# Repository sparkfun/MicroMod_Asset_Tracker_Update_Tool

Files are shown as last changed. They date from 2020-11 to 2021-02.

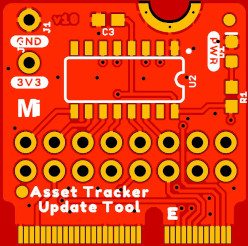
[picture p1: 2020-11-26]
img/Top.JPG

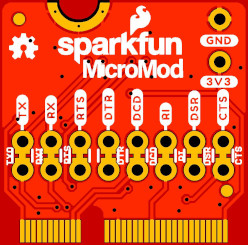
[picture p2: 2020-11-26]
img/Bottom.JPG

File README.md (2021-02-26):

# MicroMod Asset Tracker Firmware Update Tool

SparkFun MicroMod Update Tool (https://www.sparkfun.com/products/17725)

[*SparkFun MicroMod Update Tool (DEV-17725)*](https://www.sparkfun.com/products/17725)

A dummy Processor Board which will simplify firmware updates for the SARA-R5 on the [MicroMod Asset Tracker Carrier Board](https://www.sparkfun.com/products/17272).

The board carries a CH340C USB-Serial converter to act as the bridge between the USB-C interface on the carrier board and the 8-wire UART interface on the SARA-R5.

Power for the SARA can be enabled via a push-button on the carrier board.

The firmware can be updated with [EasyFlash](https://www.u-blox.com/sites/default/files/SARA-R5-FW-Update_AppNote_%28UBX-20033314%29.pdf).

The tool will also make it easy for anyone wanting to use [m-center](https://www.u-blox.com/en/product/m-center) to communicate with the SARA.

## Repository Contents

* **/Hardware** - Eagle PCB, SCH and LBR design files
* **LICENSE.md** contains the licence information

## Documentation

* **[Hookup Guide](https://learn.sparkfun.com/tutorials/micromod-update-tool-hookup-guide)** - A basic Hookup Guide for the MicroMod Update Tool.
* **[Getting Started with MicroMod](https://learn.sparkfun.com/tutorials/getting-started-with-micromod)** - A tutorial to help you get started with the MicroMod Ecosystem.
* **[Designing with MicroMod](https://learn.sparkfun.com/tutorials/designing-with-micromod)** - A tutorial to walk you through the specs of the MicroMod processor and carrier board as well as the basics of incorporating the MicroMod form factor into your own PCB designs.

## Product Versions

* **[DEV-17725](https://www.sparkfun.com/products/17725)** - Initial release of the MicroMod Update Tool

## License Information

This product is _**open source**_!

Please review the LICENSE.md file for license information.

If you have any questions or concerns on licensing, please contact technical support on our [SparkFun forums](https://forum.sparkfun.com/viewforum.php?f=152).

Distributed as-is; no warranty is given.

- Your friends at SparkFun.

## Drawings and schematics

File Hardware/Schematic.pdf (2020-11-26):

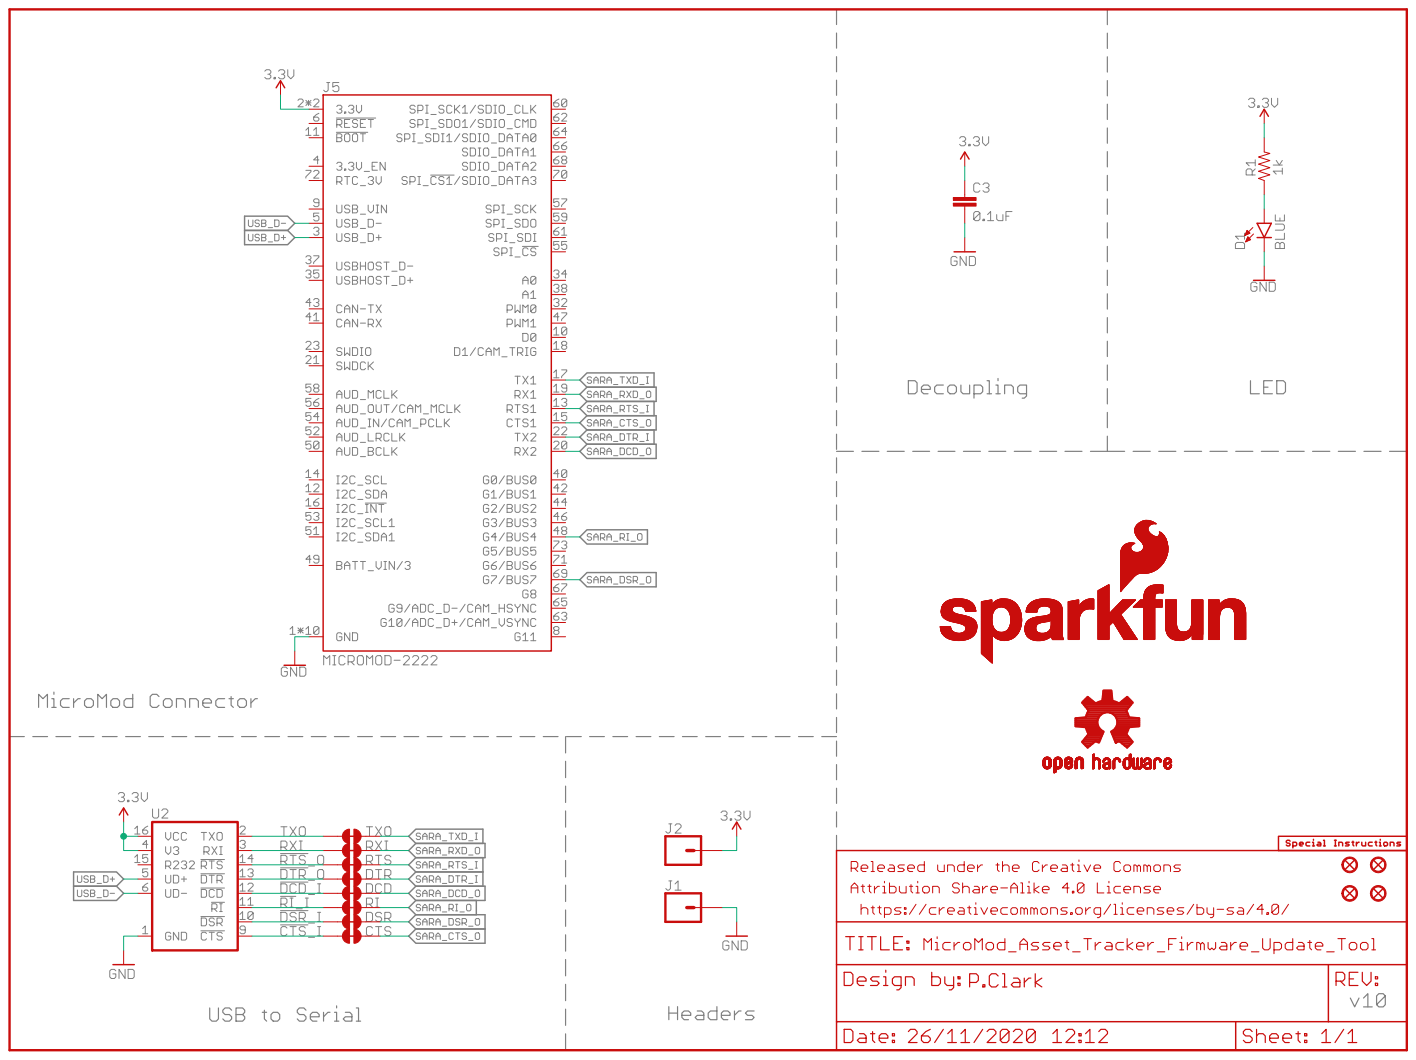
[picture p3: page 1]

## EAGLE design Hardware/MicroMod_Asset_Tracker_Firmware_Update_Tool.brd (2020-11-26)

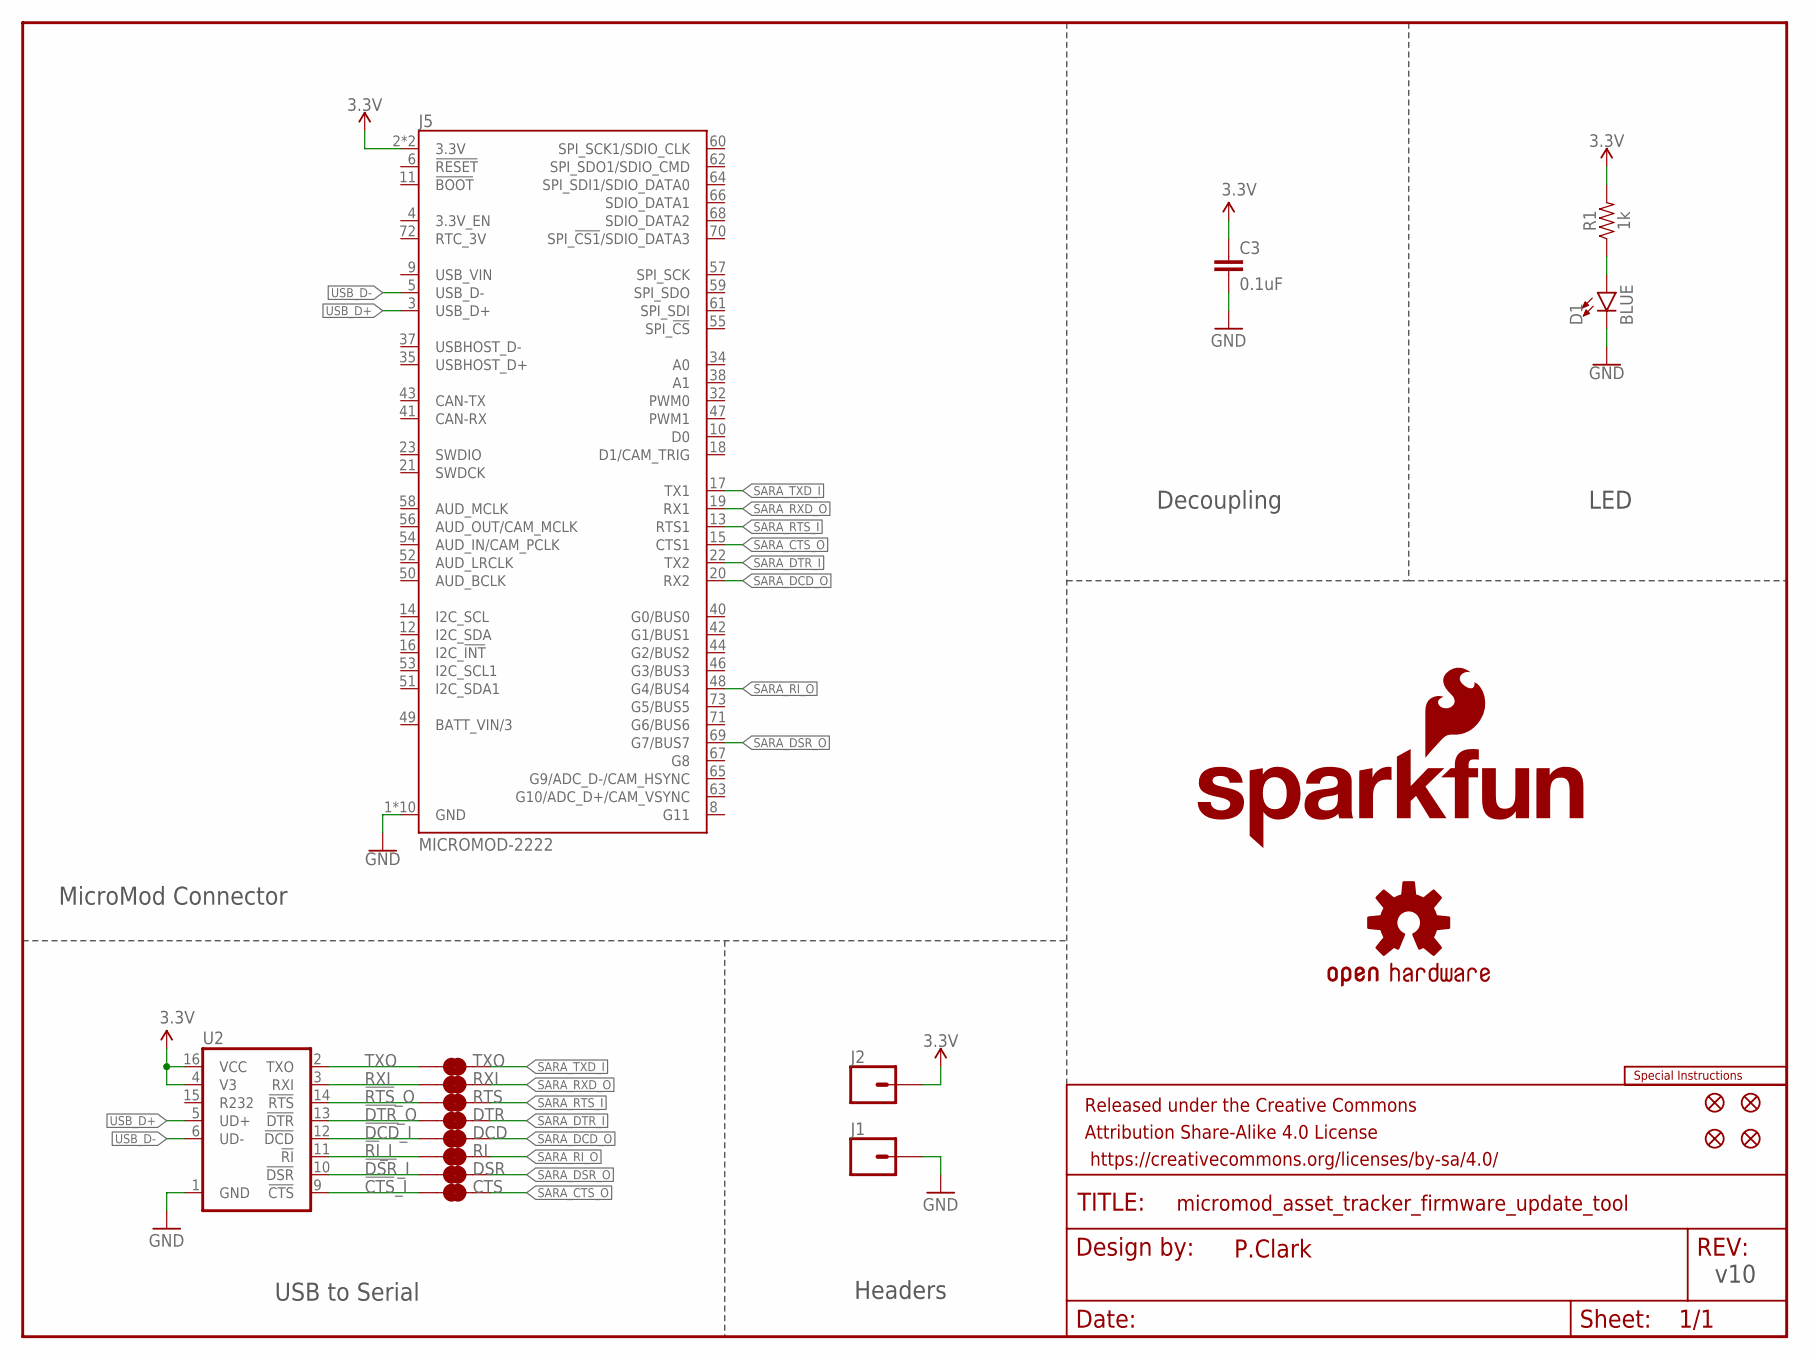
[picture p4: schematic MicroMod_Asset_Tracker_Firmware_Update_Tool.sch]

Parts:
C3: 0.1uF; 0603
CTS: JUMPER-COMBO_2_NC_TRACE; COMBO-JUMPER_2_NC_TRACE
D1: BLUE; LED-0603
DCD: JUMPER-COMBO_2_NC_TRACE; COMBO-JUMPER_2_NC_TRACE
DSR: JUMPER-COMBO_2_NC_TRACE; COMBO-JUMPER_2_NC_TRACE
DTR: JUMPER-COMBO_2_NC_TRACE; COMBO-JUMPER_2_NC_TRACE
FRAME1: FRAME-LETTER; CREATIVE_COMMONS
J1, J2: CONN_01PTH_NO_SILK_YES_STOP; 1X01_NO_SILK
J5: MICROMOD-2222; M.2-CARD-E-22
JP3, JP4, JP5, JP6: FIDUCIAL1X2; FIDUCIAL-1X2
LOGO1: OSHW-LOGOMINI; OSHW-LOGO-MINI
LOGO2: SPECIAL_INSTRUCTIONS-ORDERING; ORDERING_INSTRUCTIONS
LOGO3: SFE_LOGO_NAME_FLAME.1_INCH; SFE_LOGO_NAME_FLAME_.1
R1: 1k; 0603
RI: JUMPER-COMBO_2_NC_TRACE; COMBO-JUMPER_2_NC_TRACE
RTS: JUMPER-COMBO_2_NC_TRACE; COMBO-JUMPER_2_NC_TRACE
RXI: JUMPER-COMBO_2_NC_TRACE; COMBO-JUMPER_2_NC_TRACE
TXO: JUMPER-COMBO_2_NC_TRACE; COMBO-JUMPER_2_NC_TRACE
U2: CH340C; SO016

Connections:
3.3V: C3.1, J2.1, J5.2 (3.3V), J5.74 (3.3V), R1.2, U2.4 (V3), U2.16 (VCC)
!CTS!_I: CTS.1, CTS.3 (1), U2.9 (!CTS)
!DCD!_I: DCD.1, DCD.3 (1), U2.12 (!DCD)
!DSR!_I: DSR.1, DSR.3 (1), U2.10 (!DSR)
!DTR!_O: DTR.1, DTR.3 (1), U2.13 (!DTR)
!RI!_I: RI.1, RI.3 (1), U2.11 (!RI)
!RTS!_O: RTS.1, RTS.3 (1), U2.14 (!RTS)
GND: C3.2, D1.C, J1.1, J5.1 (GND), J5.7 (GND), J5.33 (GND), J5.36 (GND), J5.39 (GND), J5.45 (GND), J5.75 (GND), J5.GND1 (GND), J5.GND2 (GND), J5.GND3 (GND), U2.1 (GND)
unnamed: D1.A, R1.1
RXI: RXI.1, RXI.3 (1), U2.3 (RXI)
SARA_CTS_O: CTS.2, CTS.4 (2), J5.15 (CTS1)
SARA_DCD_O: DCD.2, DCD.4 (2), J5.20 (RX2)
SARA_DSR_O: DSR.2, DSR.4 (2), J5.69 (G7/BUS7)
SARA_DTR_I: DTR.2, DTR.4 (2), J5.22 (TX2)
SARA_RI_O: J5.48 (G4/BUS4), RI.2, RI.4 (2)
SARA_RTS_I: J5.13 (RTS1), RTS.2, RTS.4 (2)
SARA_RXD_O: J5.19 (RX1), RXI.2, RXI.4 (2)
SARA_TXD_I: J5.17 (TX1), TXO.2, TXO.4 (2)
TXO: TXO.1, TXO.3 (1), U2.2 (TXO)
USB_D+: J5.3 (USB_D+), U2.5 (UD+)
USB_D-: J5.5 (USB_D-), U2.6 (UD-)

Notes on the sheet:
v10
USB to Serial
P.Clark
Headers
LED
Decoupling
MicroMod Connector

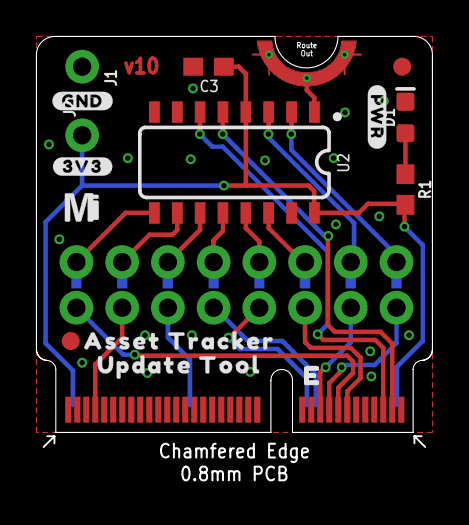
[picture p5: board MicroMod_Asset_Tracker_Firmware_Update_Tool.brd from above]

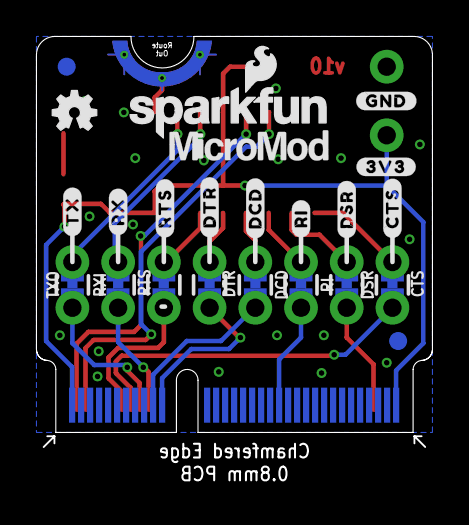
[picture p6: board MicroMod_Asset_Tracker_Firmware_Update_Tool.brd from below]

Board: 4 copper layers, 22.0 x 22.8 mm, 40 parts (23 on the bottom side), 21 nets.

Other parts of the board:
U$1: #TX#0
U$2: #RX#0
U$3, U$7: #GND#2
U$4: #DTR#0
U$5: #RI#0
U$6, U$17: #3V3#3
U$8: #PWR#0
U$9: MICROMOD_MI_LOGO_.35
U$10: ASSET_TRACKER0
U$11: UPDATE_TOOL0
U$12: MICROMOD_LOGO_.35
U$14: #CTS#0
U$18: #DSR#0
U$20: #RTS#0
U$23: #DCD#0

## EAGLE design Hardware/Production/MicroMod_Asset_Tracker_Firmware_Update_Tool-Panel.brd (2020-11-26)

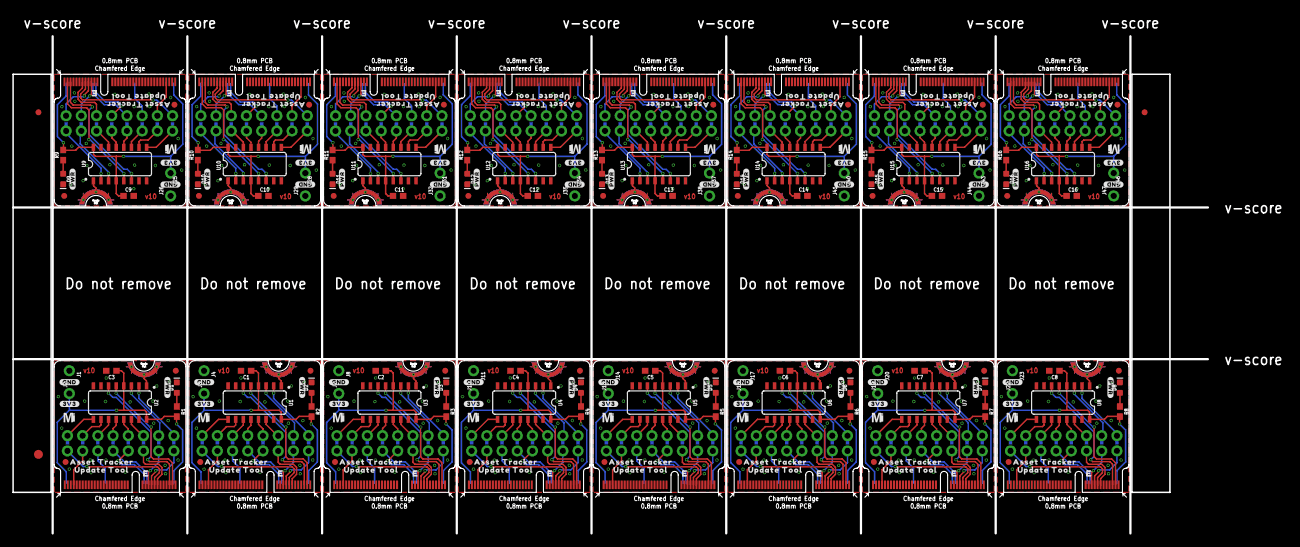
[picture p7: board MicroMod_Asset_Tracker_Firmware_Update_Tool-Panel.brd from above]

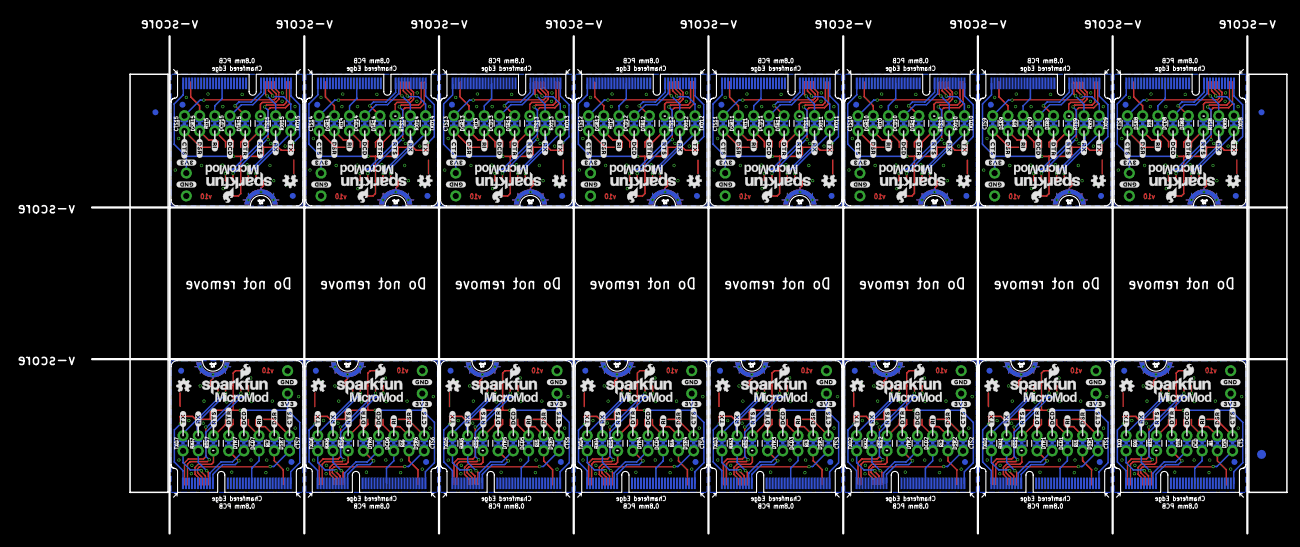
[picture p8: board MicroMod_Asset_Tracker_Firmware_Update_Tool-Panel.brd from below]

Board: 4 copper layers, 199.6 x 83.1 mm, 614 parts (371 on the bottom side), 336 nets.

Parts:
C1, C2, C3, C4, C5, C6, C7, C8, C9, C10, C11, C12, C13, C14, C15, C16: 0.1uF; 0603
CTS, CTS1, CTS2, CTS3, CTS4, CTS5, CTS6, CTS7, CTS8, CTS9, CTS10, CTS11, CTS12, CTS13, CTS14, CTS15: JUMPER-COMBO_2_NC_TRACE; COMBO-JUMPER_2_NC_TRACE
D1, D2, D3, D4, D5, D6, D7, D8, D9, D10, D11, D12, D13, D14, D15, D16: BLUE; LED-0603
DCD, DCD1, DCD2, DCD3, DCD4, DCD5, DCD6, DCD7, DCD8, DCD9, DCD10, DCD11, DCD12, DCD13, DCD14, DCD15: JUMPER-COMBO_2_NC_TRACE; COMBO-JUMPER_2_NC_TRACE
DSR, DSR1, DSR2, DSR3, DSR4, DSR5, DSR6, DSR7, DSR8, DSR9, DSR10, DSR11, DSR12, DSR13, DSR14, DSR15: JUMPER-COMBO_2_NC_TRACE; COMBO-JUMPER_2_NC_TRACE
DTR, DTR1, DTR2, DTR3, DTR4, DTR5, DTR6, DTR7, DTR8, DTR9, DTR10, DTR11, DTR12, DTR13, DTR14, DTR15: JUMPER-COMBO_2_NC_TRACE; COMBO-JUMPER_2_NC_TRACE
E$1, E$2, E$3, E$4: FIDUCIAL-1X2
E$5, E$6: FIDUCIAL-1.5X3
J1, J2, J3, J4, J7, J8, J10, J11, J13, J14, J16, J17, J19, J20, J22, J23, J25, J26, J28, J29, J31, J32, J34, J35, J37, J38, J40, J41, J43, J44, J46, J47: 1X01_NO_SILK
J5, J6, J9, J12, J15, J18, J21, J24, J27, J30, J33, J36, J39, J42, J45, J48: MICROMOD-2222; M.2-CARD-E-22
JP1, JP2, JP3, JP4, JP5, JP6, JP7, JP8, JP9, JP10, JP11, JP12, JP13, JP14, JP15, JP16, JP17, JP18, JP19, JP20, JP21, JP22, JP23, JP24, JP25, JP26, JP27, JP28, JP29, JP30, JP31, JP32, JP33, JP34, JP35, JP36, JP37, JP38, JP39, JP40, JP41, JP42, JP43, JP44, JP45, JP46, JP47, JP48, JP49, JP50, JP51, JP52, JP53, JP54, JP55, JP56, JP57, JP58, JP59, JP60, JP61, JP62, JP63, JP64: FIDUCIAL1X2; FIDUCIAL-1X2
LOGO1, LOGO2, LOGO5, LOGO7, LOGO9, LOGO11, LOGO13, LOGO15, LOGO17, LOGO19, LOGO21, LOGO23, LOGO25, LOGO27, LOGO29, LOGO31: OSHW-LOGOMINI; OSHW-LOGO-MINI
LOGO3, LOGO4, LOGO6, LOGO8, LOGO10, LOGO12, LOGO14, LOGO16, LOGO18, LOGO20, LOGO22, LOGO24, LOGO26, LOGO28, LOGO30, LOGO32: SFE_LOGO_NAME_FLAME.1_INCH; SFE_LOGO_NAME_FLAME_.1
R1, R2, R3, R4, R5, R6, R7, R8, R9, R10, R11, R12, R13, R14, R15, R16: 1k; 0603
RI, RI1, RI2, RI3, RI4, RI5, RI6, RI7, RI8, RI9, RI10, RI11, RI12, RI13, RI14, RI15: JUMPER-COMBO_2_NC_TRACE; COMBO-JUMPER_2_NC_TRACE
RTS, RTS1, RTS2, RTS3, RTS4, RTS5, RTS6, RTS7, RTS8, RTS9, RTS10, RTS11, RTS12, RTS13, RTS14, RTS15: JUMPER-COMBO_2_NC_TRACE; COMBO-JUMPER_2_NC_TRACE
RXI, RXI1, RXI2, RXI3, RXI4, RXI5, RXI6, RXI7, RXI8, RXI9, RXI10, RXI11, RXI12, RXI13, RXI14, RXI15: JUMPER-COMBO_2_NC_TRACE; COMBO-JUMPER_2_NC_TRACE
TXO, TXO1, TXO2, TXO3, TXO4, TXO5, TXO6, TXO7, TXO8, TXO9, TXO10, TXO11, TXO12, TXO13, TXO14, TXO15: JUMPER-COMBO_2_NC_TRACE; COMBO-JUMPER_2_NC_TRACE
U1, U2, U3, U4, U5, U6, U7, U8, U9, U10, U11, U12, U13, U14, U15, U16: CH340C; SO016
U$1, U$24, U$41, U$58, U$75, U$92, U$109, U$126, U$143, U$160, U$177, U$194, U$211, U$228, U$245, U$262: #TX#0
U$2, U$25, U$42, U$59, U$76, U$93, U$110, U$127, U$144, U$161, U$178, U$195, U$212, U$229, U$246, U$263: #RX#0
U$3, U$7, U$13, U$29, U$35, U$46, U$52, U$63, U$69, U$80, U$86, U$97, U$103, U$114, U$120, U$131, U$137, U$148, U$154, U$165, U$171, U$182, U$188, U$199, U$205, U$216, U$222, U$233, U$239, U$250, U$256, U$267: #GND#2
U$4, U$26, U$43, U$60, U$77, U$94, U$111, U$128, U$145, U$162, U$179, U$196, U$213, U$230, U$247, U$264: #DTR#0
U$5, U$27, U$44, U$61, U$78, U$95, U$112, U$129, U$146, U$163, U$180, U$197, U$214, U$231, U$248, U$265: #RI#0
U$6, U$15, U$17, U$28, U$36, U$45, U$53, U$62, U$70, U$79, U$87, U$96, U$104, U$113, U$121, U$130, U$138, U$147, U$155, U$164, U$172, U$181, U$189, U$198, U$206, U$215, U$223, U$232, U$240, U$249, U$257, U$266: #3V3#3
U$8, U$30, U$47, U$64, U$81, U$98, U$115, U$132, U$149, U$166, U$183, U$200, U$217, U$234, U$251, U$268: #PWR#0
U$9, U$31, U$48, U$65, U$82, U$99, U$116, U$133, U$150, U$167, U$184, U$201, U$218, U$235, U$252, U$269: MICROMOD_MI_LOGO_.35
U$10, U$32, U$49, U$66, U$83, U$100, U$117, U$134, U$151, U$168, U$185, U$202, U$219, U$236, U$253, U$270: ASSET_TRACKER0
U$11, U$33, U$50, U$67, U$84, U$101, U$118, U$135, U$152, U$169, U$186, U$203, U$220, U$237, U$254, U$271: UPDATE_TOOL0
U$12, U$34, U$51, U$68, U$85, U$102, U$119, U$136, U$153, U$170, U$187, U$204, U$221, U$238, U$255, U$272: MICROMOD_LOGO_.35
U$14, U$16, U$37, U$54, U$71, U$88, U$105, U$122, U$139, U$156, U$173, U$190, U$207, U$224, U$241, U$258: #CTS#0
U$18, U$19, U$38, U$55, U$72, U$89, U$106, U$123, U$140, U$157, U$174, U$191, U$208, U$225, U$242, U$259: #DSR#0
U$20, U$21, U$39, U$56, U$73, U$90, U$107, U$124, U$141, U$158, U$175, U$192, U$209, U$226, U$243, U$260: #RTS#0
U$22, U$23, U$40, U$57, U$74, U$91, U$108, U$125, U$142, U$159, U$176, U$193, U$210, U$227, U$244, U$261: #DCD#0

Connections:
3.3V: C3.1, J2.1, J5.2, J5.74, R1.2, U2.4, U2.16
3.3V1: C1.1, J3.1, J6.2, J6.74, R2.2, U1.4, U1.16
3.3V2: C2.1, J7.1, J9.2, J9.74, R3.2, U3.4, U3.16
3.3V3: C4.1, J10.1, J12.2, J12.74, R4.2, U4.4, U4.16
3.3V4: C5.1, J13.1, J15.2, J15.74, R5.2, U5.4, U5.16
3.3V5: C6.1, J16.1, J18.2, J18.74, R6.2, U6.4, U6.16
3.3V6: C7.1, J19.1, J21.2, J21.74, R7.2, U7.4, U7.16
3.3V7: C8.1, J22.1, J24.2, J24.74, R8.2, U8.4, U8.16
3.3V8: C9.1, J25.1, J27.2, J27.74, R9.2, U9.4, U9.16
3.3V9: C10.1, J28.1, J30.2, J30.74, R10.2, U10.4, U10.16
3.3V10: C11.1, J31.1, J33.2, J33.74, R11.2, U11.4, U11.16
3.3V11: C12.1, J34.1, J36.2, J36.74, R12.2, U12.4, U12.16
3.3V12: C13.1, J37.1, J39.2, J39.74, R13.2, U13.4, U13.16
3.3V13: C14.1, J40.1, J42.2, J42.74, R14.2, U14.4, U14.16
3.3V14: C15.1, J43.1, J45.2, J45.74, R15.2, U15.4, U15.16
3.3V15: C16.1, J46.1, J48.2, J48.74, R16.2, U16.4, U16.16
!CTS!_I: CTS.1, CTS.3, U2.9
!CTS!_I1: CTS1.1, CTS1.3, U1.9
!CTS!_I2: CTS2.1, CTS2.3, U3.9
!CTS!_I3: CTS3.1, CTS3.3, U4.9
!CTS!_I4: CTS4.1, CTS4.3, U5.9
!CTS!_I5: CTS5.1, CTS5.3, U6.9
!CTS!_I6: CTS6.1, CTS6.3, U7.9
!CTS!_I7: CTS7.1, CTS7.3, U8.9
!CTS!_I8: CTS8.1, CTS8.3, U9.9
!CTS!_I9: CTS9.1, CTS9.3, U10.9
!CTS!_I10: CTS10.1, CTS10.3, U11.9
!CTS!_I11: CTS11.1, CTS11.3, U12.9
!CTS!_I12: CTS12.1, CTS12.3, U13.9
!CTS!_I13: CTS13.1, CTS13.3, U14.9
!CTS!_I14: CTS14.1, CTS14.3, U15.9
!CTS!_I15: CTS15.1, CTS15.3, U16.9
!DCD!_I: DCD.1, DCD.3, U2.12
!DCD!_I1: DCD1.1, DCD1.3, U1.12
!DCD!_I2: DCD2.1, DCD2.3, U3.12
!DCD!_I3: DCD3.1, DCD3.3, U4.12
!DCD!_I4: DCD4.1, DCD4.3, U5.12
!DCD!_I5: DCD5.1, DCD5.3, U6.12
!DCD!_I6: DCD6.1, DCD6.3, U7.12
!DCD!_I7: DCD7.1, DCD7.3, U8.12
!DCD!_I8: DCD8.1, DCD8.3, U9.12
!DCD!_I9: DCD9.1, DCD9.3, U10.12
!DCD!_I10: DCD10.1, DCD10.3, U11.12
!DCD!_I11: DCD11.1, DCD11.3, U12.12
!DCD!_I12: DCD12.1, DCD12.3, U13.12
!DCD!_I13: DCD13.1, DCD13.3, U14.12
!DCD!_I14: DCD14.1, DCD14.3, U15.12
!DCD!_I15: DCD15.1, DCD15.3, U16.12
!DSR!_I: DSR.1, DSR.3, U2.10
!DSR!_I1: DSR1.1, DSR1.3, U1.10
!DSR!_I2: DSR2.1, DSR2.3, U3.10
!DSR!_I3: DSR3.1, DSR3.3, U4.10
!DSR!_I4: DSR4.1, DSR4.3, U5.10
!DSR!_I5: DSR5.1, DSR5.3, U6.10
!DSR!_I6: DSR6.1, DSR6.3, U7.10
!DSR!_I7: DSR7.1, DSR7.3, U8.10
!DSR!_I8: DSR8.1, DSR8.3, U9.10
!DSR!_I9: DSR9.1, DSR9.3, U10.10
!DSR!_I10: DSR10.1, DSR10.3, U11.10
!DSR!_I11: DSR11.1, DSR11.3, U12.10
!DSR!_I12: DSR12.1, DSR12.3, U13.10
!DSR!_I13: DSR13.1, DSR13.3, U14.10
!DSR!_I14: DSR14.1, DSR14.3, U15.10
!DSR!_I15: DSR15.1, DSR15.3, U16.10
!DTR!_O: DTR.1, DTR.3, U2.13
!DTR!_O1: DTR1.1, DTR1.3, U1.13
!DTR!_O2: DTR2.1, DTR2.3, U3.13
!DTR!_O3: DTR3.1, DTR3.3, U4.13
!DTR!_O4: DTR4.1, DTR4.3, U5.13
!DTR!_O5: DTR5.1, DTR5.3, U6.13
!DTR!_O6: DTR6.1, DTR6.3, U7.13
!DTR!_O7: DTR7.1, DTR7.3, U8.13
!DTR!_O8: DTR8.1, DTR8.3, U9.13
!DTR!_O9: DTR9.1, DTR9.3, U10.13
!DTR!_O10: DTR10.1, DTR10.3, U11.13
!DTR!_O11: DTR11.1, DTR11.3, U12.13
!DTR!_O12: DTR12.1, DTR12.3, U13.13
!DTR!_O13: DTR13.1, DTR13.3, U14.13
!DTR!_O14: DTR14.1, DTR14.3, U15.13
!DTR!_O15: DTR15.1, DTR15.3, U16.13
!RI!_I: RI.1, RI.3, U2.11
!RI!_I1: RI1.1, RI1.3, U1.11
!RI!_I2: RI2.1, RI2.3, U3.11
!RI!_I3: RI3.1, RI3.3, U4.11
!RI!_I4: RI4.1, RI4.3, U5.11
!RI!_I5: RI5.1, RI5.3, U6.11
!RI!_I6: RI6.1, RI6.3, U7.11
!RI!_I7: RI7.1, RI7.3, U8.11
!RI!_I8: RI8.1, RI8.3, U9.11
!RI!_I9: RI9.1, RI9.3, U10.11
!RI!_I10: RI10.1, RI10.3, U11.11
!RI!_I11: RI11.1, RI11.3, U12.11
!RI!_I12: RI12.1, RI12.3, U13.11
!RI!_I13: RI13.1, RI13.3, U14.11
!RI!_I14: RI14.1, RI14.3, U15.11
!RI!_I15: RI15.1, RI15.3, U16.11
!RTS!_O: RTS.1, RTS.3, U2.14
!RTS!_O1: RTS1.1, RTS1.3, U1.14
!RTS!_O2: RTS2.1, RTS2.3, U3.14
!RTS!_O3: RTS3.1, RTS3.3, U4.14
!RTS!_O4: RTS4.1, RTS4.3, U5.14
!RTS!_O5: RTS5.1, RTS5.3, U6.14
!RTS!_O6: RTS6.1, RTS6.3, U7.14
!RTS!_O7: RTS7.1, RTS7.3, U8.14
!RTS!_O8: RTS8.1, RTS8.3, U9.14
!RTS!_O9: RTS9.1, RTS9.3, U10.14
!RTS!_O10: RTS10.1, RTS10.3, U11.14
!RTS!_O11: RTS11.1, RTS11.3, U12.14
!RTS!_O12: RTS12.1, RTS12.3, U13.14
!RTS!_O13: RTS13.1, RTS13.3, U14.14
!RTS!_O14: RTS14.1, RTS14.3, U15.14
!RTS!_O15: RTS15.1, RTS15.3, U16.14
GND: C3.2, D1.C, J1.1, J5.1, J5.7, J5.33, J5.36, J5.39, J5.45, J5.75, J5.GND1, J5.GND2, J5.GND3, U2.1
GND1: C1.2, D2.C, J4.1, J6.1, J6.7, J6.33, J6.36, J6.39, J6.45, J6.75, J6.GND1, J6.GND2, J6.GND3, U1.1
GND2: C2.2, D3.C, J8.1, J9.1, J9.7, J9.33, J9.36, J9.39, J9.45, J9.75, J9.GND1, J9.GND2, J9.GND3, U3.1
GND3: C4.2, D4.C, J11.1, J12.1, J12.7, J12.33, J12.36, J12.39, J12.45, J12.75, J12.GND1, J12.GND2, J12.GND3, U4.1
GND4: C5.2, D5.C, J14.1, J15.1, J15.7, J15.33, J15.36, J15.39, J15.45, J15.75, J15.GND1, J15.GND2, J15.GND3, U5.1
GND5: C6.2, D6.C, J17.1, J18.1, J18.7, J18.33, J18.36, J18.39, J18.45, J18.75, J18.GND1, J18.GND2, J18.GND3, U6.1
GND6: C7.2, D7.C, J20.1, J21.1, J21.7, J21.33, J21.36, J21.39, J21.45, J21.75, J21.GND1, J21.GND2, J21.GND3, U7.1
GND7: C8.2, D8.C, J23.1, J24.1, J24.7, J24.33, J24.36, J24.39, J24.45, J24.75, J24.GND1, J24.GND2, J24.GND3, U8.1
GND8: C9.2, D9.C, J26.1, J27.1, J27.7, J27.33, J27.36, J27.39, J27.45, J27.75, J27.GND1, J27.GND2, J27.GND3, U9.1
GND9: C10.2, D10.C, J29.1, J30.1, J30.7, J30.33, J30.36, J30.39, J30.45, J30.75, J30.GND1, J30.GND2, J30.GND3, U10.1
GND10: C11.2, D11.C, J32.1, J33.1, J33.7, J33.33, J33.36, J33.39, J33.45, J33.75, J33.GND1, J33.GND2, J33.GND3, U11.1
GND11: C12.2, D12.C, J35.1, J36.1, J36.7, J36.33, J36.36, J36.39, J36.45, J36.75, J36.GND1, J36.GND2, J36.GND3, U12.1
GND12: C13.2, D13.C, J38.1, J39.1, J39.7, J39.33, J39.36, J39.39, J39.45, J39.75, J39.GND1, J39.GND2, J39.GND3, U13.1
GND13: C14.2, D14.C, J41.1, J42.1, J42.7, J42.33, J42.36, J42.39, J42.45, J42.75, J42.GND1, J42.GND2, J42.GND3, U14.1
GND14: C15.2, D15.C, J44.1, J45.1, J45.7, J45.33, J45.36, J45.39, J45.45, J45.75, J45.GND1, J45.GND2, J45.GND3, U15.1
GND15: C16.2, D16.C, J47.1, J48.1, J48.7, J48.33, J48.36, J48.39, J48.45, J48.75, J48.GND1, J48.GND2, J48.GND3, U16.1
unnamed: D2.A, R2.1
unnamed: D3.A, R3.1
unnamed: D1.A, R1.1
unnamed: D4.A, R4.1
unnamed: D5.A, R5.1
unnamed: D6.A, R6.1
unnamed: D7.A, R7.1
unnamed: D8.A, R8.1
unnamed: D9.A, R9.1
unnamed: D10.A, R10.1
unnamed: D11.A, R11.1
unnamed: D12.A, R12.1
unnamed: D13.A, R13.1
unnamed: D14.A, R14.1
unnamed: D15.A, R15.1
unnamed: D16.A, R16.1
RXI: RXI.1, RXI.3, U2.3
RXI1: RXI1.1, RXI1.3, U1.3
RXI2: RXI2.1, RXI2.3, U3.3
RXI3: RXI3.1, RXI3.3, U4.3
RXI4: RXI4.1, RXI4.3, U5.3
RXI5: RXI5.1, RXI5.3, U6.3
RXI6: RXI6.1, RXI6.3, U7.3
RXI7: RXI7.1, RXI7.3, U8.3
RXI8: RXI8.1, RXI8.3, U9.3
RXI9: RXI9.1, RXI9.3, U10.3
RXI10: RXI10.1, RXI10.3, U11.3
RXI11: RXI11.1, RXI11.3, U12.3
RXI12: RXI12.1, RXI12.3, U13.3
RXI13: RXI13.1, RXI13.3, U14.3
RXI14: RXI14.1, RXI14.3, U15.3
RXI15: RXI15.1, RXI15.3, U16.3
SARA_CTS_O: CTS.2, CTS.4, J5.15
SARA_CTS_O1: CTS1.2, CTS1.4, J6.15
SARA_CTS_O2: CTS2.2, CTS2.4, J9.15
SARA_CTS_O3: CTS3.2, CTS3.4, J12.15
SARA_CTS_O4: CTS4.2, CTS4.4, J15.15
SARA_CTS_O5: CTS5.2, CTS5.4, J18.15
SARA_CTS_O6: CTS6.2, CTS6.4, J21.15
SARA_CTS_O7: CTS7.2, CTS7.4, J24.15
SARA_CTS_O8: CTS8.2, CTS8.4, J27.15
SARA_CTS_O9: CTS9.2, CTS9.4, J30.15
SARA_CTS_O10: CTS10.2, CTS10.4, J33.15
SARA_CTS_O11: CTS11.2, CTS11.4, J36.15
SARA_CTS_O12: CTS12.2, CTS12.4, J39.15
SARA_CTS_O13: CTS13.2, CTS13.4, J42.15
SARA_CTS_O14: CTS14.2, CTS14.4, J45.15
SARA_CTS_O15: CTS15.2, CTS15.4, J48.15
SARA_DCD_O: DCD.2, DCD.4, J5.20
SARA_DCD_O1: DCD1.2, DCD1.4, J6.20
SARA_DCD_O2: DCD2.2, DCD2.4, J9.20
SARA_DCD_O3: DCD3.2, DCD3.4, J12.20
SARA_DCD_O4: DCD4.2, DCD4.4, J15.20
SARA_DCD_O5: DCD5.2, DCD5.4, J18.20
SARA_DCD_O6: DCD6.2, DCD6.4, J21.20
SARA_DCD_O7: DCD7.2, DCD7.4, J24.20
SARA_DCD_O8: DCD8.2, DCD8.4, J27.20
SARA_DCD_O9: DCD9.2, DCD9.4, J30.20
SARA_DCD_O10: DCD10.2, DCD10.4, J33.20
SARA_DCD_O11: DCD11.2, DCD11.4, J36.20
SARA_DCD_O12: DCD12.2, DCD12.4, J39.20
SARA_DCD_O13: DCD13.2, DCD13.4, J42.20
SARA_DCD_O14: DCD14.2, DCD14.4, J45.20
SARA_DCD_O15: DCD15.2, DCD15.4, J48.20
SARA_DSR_O: DSR.2, DSR.4, J5.69
SARA_DSR_O1: DSR1.2, DSR1.4, J6.69
SARA_DSR_O2: DSR2.2, DSR2.4, J9.69
SARA_DSR_O3: DSR3.2, DSR3.4, J12.69
SARA_DSR_O4: DSR4.2, DSR4.4, J15.69
SARA_DSR_O5: DSR5.2, DSR5.4, J18.69
SARA_DSR_O6: DSR6.2, DSR6.4, J21.69
SARA_DSR_O7: DSR7.2, DSR7.4, J24.69
SARA_DSR_O8: DSR8.2, DSR8.4, J27.69
SARA_DSR_O9: DSR9.2, DSR9.4, J30.69
SARA_DSR_O10: DSR10.2, DSR10.4, J33.69
SARA_DSR_O11: DSR11.2, DSR11.4, J36.69
SARA_DSR_O12: DSR12.2, DSR12.4, J39.69
SARA_DSR_O13: DSR13.2, DSR13.4, J42.69
SARA_DSR_O14: DSR14.2, DSR14.4, J45.69
SARA_DSR_O15: DSR15.2, DSR15.4, J48.69
SARA_DTR_I: DTR.2, DTR.4, J5.22
SARA_DTR_I1: DTR1.2, DTR1.4, J6.22
SARA_DTR_I2: DTR2.2, DTR2.4, J9.22
SARA_DTR_I3: DTR3.2, DTR3.4, J12.22
SARA_DTR_I4: DTR4.2, DTR4.4, J15.22
SARA_DTR_I5: DTR5.2, DTR5.4, J18.22
SARA_DTR_I6: DTR6.2, DTR6.4, J21.22
SARA_DTR_I7: DTR7.2, DTR7.4, J24.22
SARA_DTR_I8: DTR8.2, DTR8.4, J27.22
SARA_DTR_I9: DTR9.2, DTR9.4, J30.22
SARA_DTR_I10: DTR10.2, DTR10.4, J33.22
SARA_DTR_I11: DTR11.2, DTR11.4, J36.22
SARA_DTR_I12: DTR12.2, DTR12.4, J39.22
SARA_DTR_I13: DTR13.2, DTR13.4, J42.22
SARA_DTR_I14: DTR14.2, DTR14.4, J45.22
SARA_DTR_I15: DTR15.2, DTR15.4, J48.22
SARA_RI_O: J5.48, RI.2, RI.4
SARA_RI_O1: J6.48, RI1.2, RI1.4
SARA_RI_O2: J9.48, RI2.2, RI2.4
SARA_RI_O3: J12.48, RI3.2, RI3.4
SARA_RI_O4: J15.48, RI4.2, RI4.4
SARA_RI_O5: J18.48, RI5.2, RI5.4
SARA_RI_O6: J21.48, RI6.2, RI6.4
SARA_RI_O7: J24.48, RI7.2, RI7.4
SARA_RI_O8: J27.48, RI8.2, RI8.4
SARA_RI_O9: J30.48, RI9.2, RI9.4
SARA_RI_O10: J33.48, RI10.2, RI10.4
SARA_RI_O11: J36.48, RI11.2, RI11.4
SARA_RI_O12: J39.48, RI12.2, RI12.4
SARA_RI_O13: J42.48, RI13.2, RI13.4
SARA_RI_O14: J45.48, RI14.2, RI14.4
SARA_RI_O15: J48.48, RI15.2, RI15.4
SARA_RTS_I: J5.13, RTS.2, RTS.4
SARA_RTS_I1: J6.13, RTS1.2, RTS1.4
SARA_RTS_I2: J9.13, RTS2.2, RTS2.4
SARA_RTS_I3: J12.13, RTS3.2, RTS3.4
SARA_RTS_I4: J15.13, RTS4.2, RTS4.4
SARA_RTS_I5: J18.13, RTS5.2, RTS5.4
SARA_RTS_I6: J21.13, RTS6.2, RTS6.4
SARA_RTS_I7: J24.13, RTS7.2, RTS7.4
SARA_RTS_I8: J27.13, RTS8.2, RTS8.4
SARA_RTS_I9: J30.13, RTS9.2, RTS9.4
SARA_RTS_I10: J33.13, RTS10.2, RTS10.4
SARA_RTS_I11: J36.13, RTS11.2, RTS11.4
SARA_RTS_I12: J39.13, RTS12.2, RTS12.4
SARA_RTS_I13: J42.13, RTS13.2, RTS13.4
SARA_RTS_I14: J45.13, RTS14.2, RTS14.4
SARA_RTS_I15: J48.13, RTS15.2, RTS15.4
SARA_RXD_O: J5.19, RXI.2, RXI.4
SARA_RXD_O1: J6.19, RXI1.2, RXI1.4
SARA_RXD_O2: J9.19, RXI2.2, RXI2.4
SARA_RXD_O3: J12.19, RXI3.2, RXI3.4
SARA_RXD_O4: J15.19, RXI4.2, RXI4.4
SARA_RXD_O5: J18.19, RXI5.2, RXI5.4
SARA_RXD_O6: J21.19, RXI6.2, RXI6.4
SARA_RXD_O7: J24.19, RXI7.2, RXI7.4
SARA_RXD_O8: J27.19, RXI8.2, RXI8.4
SARA_RXD_O9: J30.19, RXI9.2, RXI9.4
SARA_RXD_O10: J33.19, RXI10.2, RXI10.4
SARA_RXD_O11: J36.19, RXI11.2, RXI11.4
SARA_RXD_O12: J39.19, RXI12.2, RXI12.4
SARA_RXD_O13: J42.19, RXI13.2, RXI13.4
SARA_RXD_O14: J45.19, RXI14.2, RXI14.4
SARA_RXD_O15: J48.19, RXI15.2, RXI15.4
SARA_TXD_I: J5.17, TXO.2, TXO.4
SARA_TXD_I1: J6.17, TXO1.2, TXO1.4
SARA_TXD_I2: J9.17, TXO2.2, TXO2.4
SARA_TXD_I3: J12.17, TXO3.2, TXO3.4
SARA_TXD_I4: J15.17, TXO4.2, TXO4.4
SARA_TXD_I5: J18.17, TXO5.2, TXO5.4
SARA_TXD_I6: J21.17, TXO6.2, TXO6.4
SARA_TXD_I7: J24.17, TXO7.2, TXO7.4
SARA_TXD_I8: J27.17, TXO8.2, TXO8.4
SARA_TXD_I9: J30.17, TXO9.2, TXO9.4
SARA_TXD_I10: J33.17, TXO10.2, TXO10.4
SARA_TXD_I11: J36.17, TXO11.2, TXO11.4
SARA_TXD_I12: J39.17, TXO12.2, TXO12.4
SARA_TXD_I13: J42.17, TXO13.2, TXO13.4
SARA_TXD_I14: J45.17, TXO14.2, TXO14.4
SARA_TXD_I15: J48.17, TXO15.2, TXO15.4
TXO: TXO.1, TXO.3, U2.2
TXO1: TXO1.1, TXO1.3, U1.2
TXO2: TXO2.1, TXO2.3, U3.2
TXO3: TXO3.1, TXO3.3, U4.2
TXO4: TXO4.1, TXO4.3, U5.2
TXO5: TXO5.1, TXO5.3, U6.2
TXO6: TXO6.1, TXO6.3, U7.2
TXO7: TXO7.1, TXO7.3, U8.2
TXO8: TXO8.1, TXO8.3, U9.2
TXO9: TXO9.1, TXO9.3, U10.2
TXO10: TXO10.1, TXO10.3, U11.2
TXO11: TXO11.1, TXO11.3, U12.2
TXO12: TXO12.1, TXO12.3, U13.2
TXO13: TXO13.1, TXO13.3, U14.2
TXO14: TXO14.1, TXO14.3, U15.2
TXO15: TXO15.1, TXO15.3, U16.2
USB_D+: J5.3, U2.5
USB_D+1: J6.3, U1.5
USB_D+2: J9.3, U3.5
USB_D+3: J12.3, U4.5
USB_D+4: J15.3, U5.5
USB_D+5: J18.3, U6.5
USB_D+6: J21.3, U7.5
USB_D+7: J24.3, U8.5
USB_D+8: J27.3, U9.5
USB_D+9: J30.3, U10.5
USB_D+10: J33.3, U11.5
USB_D+11: J36.3, U12.5
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

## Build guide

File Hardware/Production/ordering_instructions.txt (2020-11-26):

panel size, 194x70mm
PCB thickness, 0.8mm
number of layers, 2
soldermask color, Red
silkscreen color, White
oz copper, 1oz
finish, ENIG
stencils, top
pcs per panel, 16
min trace width, 0.2540mm / 0.0100in
min drill size, 0.2000mm / 0.0079in

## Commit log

2020-10-19 Added the Eagle files
    [MicroMod_Asset_Tracker_Firmware_Update_Tool.brd, MicroMod_Asset_Tracker_Firmware_Update_Tool.sch]
2020-10-20 Adding production panel (8x2)
    [MicroMod_Asset_Tracker_Firmware_Update_Tool-Panel.GBL, MicroMod_Asset_Tracker_Firmware_Update_Tool-Panel.GBO, MicroMod_Asset_Tracker_Firmware_Update_Tool-Panel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]
2020-10-22 Changed to the CH340C
    [MicroMod_Asset_Tracker_Firmware_Update_Tool-Panel.brd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]
2020-11-26 Updates for v10
    [MicroMod_Asset_Tracker_Firmware_Update_Tool-Panel.brd, MicroMod_Asset_Tracker_Firmware_Update_Tool.brd, MicroMod_Asset_Tracker_Firmware_Update_Tool.sch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]

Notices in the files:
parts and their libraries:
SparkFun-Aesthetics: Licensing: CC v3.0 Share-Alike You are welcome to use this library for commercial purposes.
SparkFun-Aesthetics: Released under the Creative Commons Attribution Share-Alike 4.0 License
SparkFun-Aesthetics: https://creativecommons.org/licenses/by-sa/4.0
